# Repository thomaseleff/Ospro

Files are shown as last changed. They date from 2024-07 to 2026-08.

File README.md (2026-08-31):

<html>
    <body>
        <p align="center">
            
        </p>
        <h1 align="center">Ospro</font></h1>
        <p align="center">Better than decent, open source espresso.</p>
    </body>
</html>

> [!IMPORTANT]
> The resources within this repository are under active development and are expected to change significantly over time without guarantee of backwards compatibility.

## Features
- Data logging of espresso extraction metrics (includes temperature and pressure)
- Temperature control via PID-algorithm
- Pressure profiling via PID-algorithm (in-progress)
- Self-hosted web-interface for browsing historical extractions and creating & sharing espresso extraction profiles (upcoming)

**Ospro** is available at an astounding low cost,
- The cheapest commercial-standard espresso machine with a configurable temperature PID, Rancilio Silvia PID Espresso Machine at **```$1,195 USD```**
- The cheapest with fully-integrated software, Decent DE1PRO at **```$3,699 USD```**
- The cheapest with manual pressure control, Rocket R Nine One Dual-Boiler Espresso Machine at **```$6,500 USD```**

The all-in **Ospro** cost-to-build, including the Gaggia Classic (Evo) Pro, competition-level accessories, hardware and software is less than **```$1,000 USD```**.

## Table of contents
- [Parts](./parts/README.md)
- [Guides](./guides/README.md)

# Installation
Instructions for setting-up the Raspberry Pi operating system and Ospro software application.

## Requirements
- Raspberry Pi OS Bookworm (Python 3.11) or Trixie (Python 3.13)
- Python >=3.11
- [uv](https://docs.astral.sh/uv/) for dependency management (dependencies are declared in [pyproject.toml](pyproject.toml))
- Internet connection

## Instructions
1. Flash a micro-SD card with the Raspberry PI OS version from 2019-07-12 using the official [Raspberry Pi Imager](https://www.raspberrypi.com/software/).
2. Once finished, insert the micro-SD card into the Raspberry Pi, then boot.
3. Once the boot process completes, update the software packages by running the following commands in the terminal,
```
sudo apt update
sudo apt full-upgrade
```
4. Open the Raspberry Pi config and enable SPI and I2C. Open the config by running the following command in the terminal,
```
sudo raspi-config
```
5. Reboot.
6. Once the reboot process completes, open the terminal. Navigate to the location of the USB flash drive storage.
```
cd /media/{user}/{usb-mass-storage-device-name}
```
7. Next, clone the main branch of the **Ospro** repository.
```
git clone --branch main https://github.com/thomaseleff/Ospro.git
```
8. Install [uv](https://docs.astral.sh/uv/) (if not already installed).
```
curl -LsSf https://astral.sh/uv/install.sh | sh
```
9. Navigate into the repository and install the Python requirements. On the Raspberry Pi, include the `rpi` extra for the hardware libraries.
```
cd Ospro
uv sync --extra rpi
```
> On non-Raspberry-Pi machines (e.g. for development), install without the extra: `uv sync`.
>
> When running from a USB flash drive, its filesystem (e.g. FAT32/exFAT) may not support the links `uv` needs for the virtual environment. Point the environment at the home directory (on the internal SD card) before syncing:
> ```
> export UV_PROJECT_ENVIRONMENT=/home/{user}/.venv
> ```
10. Run **Ospro**.
```
uv run python main.py
```

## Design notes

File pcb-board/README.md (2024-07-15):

> [!CAUTION]
> The following resources are provided for informational purposes only. The publisher(s) of the resources assume(s) no responsibility for any personal or property damage, loss of functionality or warranty, or other consequences resulting from the use of the guides. Users proceed at their own risk and are advised to seek professional assistance.

# Board
The board guide contains the breadboard layout assets to make the hardware required for the Ospro software application.

## Table of contents
- [Main board (prototype)](main_board_prototype.fzz)

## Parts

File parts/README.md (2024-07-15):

# Parts
Recommended Gaggia Classic (Evo) Pro espresso machine hardware & accessories as well as the full required hardware and electrical components to complete all hardware and software modifications within [Guides](/guides/README.md). Aside from listing the hardware, the following tables also provide a break-down of the total-cost-to-build.

## Espresso machine hardware & accessories

| Recommended | Qty | Price | Source |
| --- | --- | --- | --- |
| Gaggia Classic (Evo) Pro | 1 | $449.99 | [Whole Latte Love](https://www.wholelattelove.com/products/gaggia-classic-evo-pro-semi-automatic-espresso-machine) |
| IMS Nanotech Gaggia Classic Shower Screen | 1 | $29.99 | [Whole Latte Love](https://www.wholelattelove.com/products/ims-nanotech-gaggia-classic-shower-screen) |
| Gaggia Bottomless Filter Holder | 1 | $36.13 | [Amazon](https://www.amazon.com/gp/product/B00JF9WCBW/ref=ox_sc_act_title_5?smid=A1F6X90FK1MD60&psc=1) |
| Baristapro 18g Nanotech Precision Portafilter Basket | 1 | $29.95 | [Whole Latte Love](https://www.wholelattelove.com/products/baristapro-18g-nanotech-precision-portafilter-basket) |
| Small Kitchen Scale, 500g/ 0.01g | 1 | $13.95 | [Amazon](https://www.amazon.com/gp/product/B082CKHBWC/ref=ox_sc_act_title_1?smid=A2E2CPICPY6E5R&th=1) |
| Metallurgica Motta Black Beechwood Competition Tamper, 58.4 mm | 1 | $42.95 | [Amazon](https://www.amazon.com/Motta-Black-Competition-Tamper-ITALY/dp/B077VP7W5K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) |
| **Total** | | **$602.96** | |

| Optional | Qty | Price | Source |
| --- | --- | --- | --- |
| Caffewerks Silicone Group Gasket | 1 | $7.50 | [Whole Latte Love](https://www.wholelattelove.com/products/caffewerks-silicone-group-gasket-73-x-57-x-8-5mm) |
| Normcore 58.5mm Puck Screen | 1 | $14.99 | [Amazon](https://www.amazon.com/gp/product/B09DDC7KMQ/ref=ox_sc_act_title_2?smid=A376RVBG8KFV1A&psc=1) |
| 2 oz Glass Spray Bottles | 1 | $7.99 | [Amazon](https://www.amazon.com/Amber-Glass-Bottles-Essential-Bottle/dp/B08252DJHN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) |
| Metallurgica Motta Leveling Tool, 58.5 mm | 1 | $42.95 | [Amazon](https://www.amazon.com/Metallurgica-Motta-Barista-Espresso-Leveling/dp/B08NF837P9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) |
| **Total** | | **$73.43**  | |

## Primary hardware components

| Key | Description |
| --- | --- |
|:computer: | Computer hardware |
|:thermometer: | Boiler stabilization hardware |
|:droplet: | Temperature controller hardware  |
|:chart_with_upwards_trend:  | Pressure controller hardware |

| Key | Part | Qty | Premium | Source | Budget  | Source |
| ----- | --- | --- | --- | --- | --- | --- |
| 💻 | Raspberry Pi 4 Model B | 1 | $35.00  | [Adafruit](https://www.adafruit.com/product/4295) | $35.00  | Same as premium |
| 💻 | SanDisk 16GB Ultra microSDHC UHS-I memory card with adapter | 1 | $8.45 | [Amazon](https://www.amazon.com/Sandisk-Ultra-Micro-UHS-I-Adapter/dp/B073K14CVB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) | $4.96 | [AliExpress](https://www.aliexpress.us/item/3256805257283122.html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) |
| 💻 | Raspberry Pi official power supply | 1 | $7.95 | [Adafruit](https://www.adafruit.com/product/4298) | $4.72 | [AliExpress](https://www.aliexpress.us/item/3256802124078165.html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) |
| 💻 | 7 inch 1024x600 IPS, touchscreen display mini HDMI monitor | 1 | $79.99  | [Amazon](https://www.amazon.com/APROTII-Raspberry-1024x600-Capacitive-Touchscreen/dp/B0BBT2SLKS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) | $51.43  | [AliExpress](https://www.aliexpress.us/item/3256804751932026.html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) |
| 💻 | Micro HDMI to mini HDMI cable | 1 | $0.00 | (included with the display) | $0.00 | (included with the display) |
| 💻 | SanDisk 16GB Ultra Fit USB 3.1 flash drive | 1 | $7.29 | [Amazon](https://www.amazon.com/dp/B077Y149DL/ref=twister_B0BQ5H62TT?_encoding=UTF8&th=1) | $4.65 | [AliExpress](https://www.aliexpress.us/item/2255800045699642.html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) |
| 💻 | 40 pin GPIO T-Cobbler breakout board with ribbon cable | 1 | $7.95 | [Adafruit](https://www.adafruit.com/product/2028) | $3.11 | [AliExpress](https://www.aliexpress.us/item/3256803505972324.html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) |
| 💻 | Full size breadboard | 1 | $5.95 | [Adafruit](https://www.adafruit.com/product/239) | 3.89 | [AliExpress](https://www.aliexpress.us/item/3256805782396682.html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) |
| 💻 | Various colored solid core wire | 1 | $15.95  | [Adafruit](https://www.adafruit.com/product/1311) | 13.29 | [AliExpress](https://www.aliexpress.us/item/2251832718635676.html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) |
| 💻 | 2 Pin 5 MM PCB mount screw terminal block | 3 | $8.29 | [Amazon](https://www.amazon.com/Pieces-Pinch-Mount-Terminal-Connector/dp/B01MT4LC0F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) | 3.83 | [AliExpress](https://www.aliexpress.us/item/2251832567524817.html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) |
| 💻 | 8 x 10 1/8 IN thick acrylic sheet | 1 | $4.58 | [Menards](https://www.menards.com/main/doors-windows-millwork/acrylic-glass-sheets/amerilux-0-060-thick-non-glare-acrylic-sheets/nga8x10x050/p-1539107081822-c-7551.htm) | $4.58 | Same as premium |
| 💻 | 3/4 IN x 10 FT roll of removable foam mounting tape | 1 | $3.49 | [Menards](https://www.menards.com/main/paint/adhesives-glue-tape/tape/mounting-tape/duck-reg-0-75-x-10-removable-double-sided-foam-mounting-tape/1098147/p-1444442289319-c-1318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) | $3.49 | Same as premium |
| 💻 | Black nylon machine screw and stand-off set - M2.5 thread | 1 | $16.95  | [Adafruit](https://www.adafruit.com/product/3299) | 3.13 | [AliExpress](https://www.aliexpress.us/item/3256803861233916.html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) |
| 💻 | 3D printed enclosure | 1 | $0.00 | OnShape (in-progress) | $0.00 | Same as premium |
| 💻 | 3D printed front end-cap | 1 | $0.00 | OnShape (in-progress) | $0.00 | Same as premium |
| 💻 | 3D printed rear end-cap | 1 | $0.00 | OnShape (in-progress) | $0.00 | Same as premium |
| 💧 | Adafruit K-type thermocouple amplifier - MAX31855 | 1 | $14.95  | [Adafruit](https://www.adafruit.com/product/269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) | $3.94 | [AliExpress](https://www.aliexpress.us/item/3256801134000615.html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) |
| 💧 | K Type thermocouple with M4 Thread | 1 | $7.99 | [Amazon](https://www.amazon.com/gp/product/B07BW7XCB2/ref=ppx_yo_dt_b_search_asin_title?ie=UTF8&psc=1) | $4.34 | [AliExpress](https://www.aliexpress.us/item/3256805310471537.html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) |
| 💧 | Solid state relay 40DA DC SSR | 1 | $14.99  | [Amazon](https://www.amazon.com/gp/product/B01MCWO35P/ref=ppx_yo_dt_b_search_asin_title?ie=UTF8&psc=1) | $3.99 | [AliExpress](https://www.aliexpress.us/item/3256805804433987.html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) |
| 💧 | 220 ohm resistor | 1 | $0.75 | [Adafruit](https://www.adafruit.com/product/2780) | 2.11 | [AliExpress](https://www.aliexpress.us/item/3256801905005351.html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) |
| 💧 | Blue LED | 1 | $5.95 | [Adafruit](https://www.adafruit.com/product/780) | 1.84 | [AliExpress](https://www.aliexpress.us/item/2251832687046532.html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) |
| 💧 | Male 16 AWG spade-connector | 2 | $1.39 | [Menards](https://www.menards.com/main/electrical/electrical-tools-accessories/terminals-connectors/termination-connectors/gardner-bender-reg-16-14-awg-blue-spade-wire-termina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) | $1.39 | Same as premium |
| 💧 | Male 16 AWG disconnect | 2 | $1.34 | [Menards](https://www.menards.com/main/electrical/electrical-tools-accessories/terminals-connectors/termination-connectors/gardner-bender-reg-yellow-male-wire-disconnect/20-14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) | $1.34 | Same as premium |
| 💧 | 1/4 IN OD x 10 FT utility copper tubing | 1 | $6.28 | [Home Depot](https://www.homedepot.com/p/Everbilt-1-4-in-O-D-x-10-ft-Copper-Soft-Type-Refrigeration-Coil-D-04010PS/100344517) | $6.28 | Same as premium |
| 💧 | 1/4 IN OD Compression x 1/4 IN FIP brass adapter fitting | 2 | $9.08 | [Home Depot](https://www.homedepot.com/p/Everbilt-1-4-in-OD-Compression-x-1-4-in-FIP-Brass-Adapter-Fitting-801189/207176825) | $9.08 | Same as premium |
| 💧 | 1/8 IN Barb x 1/4 IN MIP brass adapter fitting | 2 | $8.22 | [Home Depot](https://www.homedepot.com/p/Everbilt-1-8-in-Barb-x-1-4-in-MIP-Brass-Adapter-Fitting-800049/300096270) | $8.22 | Same as premium |
| 💧 | High-temperature silicone foam, 12 IN x 12 IN, 1/4 IN thick, extra soft | 1 | $48.90  | [McMaster-Carr](https://www.mcmaster.com/8608K54/) | $9.28 | [AliExpress](https://www.aliexpress.us/item/3256801394757303.html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) |
| 💧 | High-pressure reinforced silicone rubber tubing for food and beverage, 1/8 IN ID, 23/64 IN OD, 2 FT Length | 1 | $5.55 | [Ebay](https://www.ebay.com/itm/404190884353) | $5.55 | Same as premium |
| 💧 | 5/16 - 5/8 IN stainless steel hose clamp | 4 | $7.52 | [Home Depot](https://www.homedepot.com/p/Everbilt-5-16-5-8-in-Stainless-Steel-Hose-Clamp-6260294/202309384) | $7.52 | Same as premium |
| 💧 | 12 IN Zip-ties | 4 | $8.49 | [Amazon](https://www.amazon.com/HS-Protected-Locking-Plastic-Outdoor/dp/B078NQBSJR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) | $8.49 | [Amazon](https://www.amazon.com/HS-Protected-Locking-Plastic-Outdoor/dp/B078NQBSJR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) |
| 📈 | Adafruit 4-channel I2C-safe Bi-directional logic level converter - BSS138 | 1 | $3.95 | [Adafruit](https://www.adafruit.com/product/757) | $3.30 | [AliExpress](https://www.aliexpress.us/item/2251832174884554.html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) |
| 📈 | Adafruit 16-Bit ADC - 4 Channel with programmable gain amplifier - ADS1115 | 1 | $14.95  | [Adafruit](https://www.adafruit.com/product/1085) | $2.35 | [AliExpress](https://www.aliexpress.us/item/3256805787660372.html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) |
| 📈 | Pressure transducer 1/8 IN NPT thread stainless steel (500 PSI) | 1 | $15.99  | [Amazon](https://www.amazon.com/gp/product/B00RCPDE40/ref=ppx_yo_dt_b_asin_title_o00_s00?ie=UTF8&th=1) | $11.37  | [AliExpress](https://www.aliexpress.us/item/2251832873594937.html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) |
| 📈 | 1/4 IN x 1/8 IN FIP brass reducing coupling fitting | 1 | $4.18 | [Home Depot](https://www.homedepot.com/p/Everbilt-1-4-in-x-1-8-in-FIP-Brass-Reducing-Coupling-Fitting-802059/300096128) | $4.18 | Same as premium |
| 📈 | 25 W 100 OHM high power wirewound rheostat | 1 | $16.99  | [Amazon](https://www.amazon.com/gp/product/B012S6HSJ4/ref=ppx_yo_dt_b_search_asin_title?ie=UTF8&th=1) | $9.90 | [AliExpress](https://www.aliexpress.us/item/3256805007421993.html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) |
| 📈 | 16 AWG 600 V wire (6 FT length) | 1 | $18.89  | [Amazon](https://www.amazon.com/Silicone-Flexible-Stranded-Strands-MILAPEAK/dp/B07CMYVF3J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) | 6.52 | [AliExpress](https://www.aliexpress.us/item/3256805920023343.html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) |
| 📈 | 1/4 IN PET expandable braided sleeving (22 IN length) | 1 | $7.99 | [Amazon](https://www.amazon.com/gp/product/B081MWG8YW/ref=ppx_yo_dt_b_search_asin_title?ie=UTF8&th=1) | 2.09 | [AliExpress](https://www.aliexpress.us/item/3256802548623899.html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) |
| 📈 | Female 16 AWG disconnect | 4 | $2.57 | [Menards](https://www.menards.com/main/electrical/electrical-tools-accessories/terminals-connectors/termination-connectors/gardner-bender-reg-16-14-awg-female-wire-disconnect-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) | $2.57 | Same as premium |
| 📈 | Male 16 AWG disconnect | 2 | $1.34 | [Menards](https://www.menards.com/main/electrical/electrical-tools-accessories/terminals-connectors/termination-connectors/gardner-bender-reg-yellow-male-wire-disconnect/20-14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) | $1.34 | Same as premium |
| 📈 | 1/4 IN shrink wrap (1.5 IN length) | 2 | $8.79 | [Amazon](https://www.amazon.com/gp/product/B07QM8249H/ref=ppx_yo_dt_b_search_asin_title?ie=UTF8&th=1) | 3.07 | [AliExpress](https://www.aliexpress.us/item/3256805006045816.html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) |
| 📈 | [3D printed enclosure](https://cad.onshape.com/documents/64f241d8e2f6bf438afa5b67/w/5135805c6b87d0dba22b77a7/e/a455f75cacce987199a97961) | 1 | $0.00 | [OnShape](https://cad.onshape.com/documents/64f241d8e2f6bf438afa5b67/w/5135805c6b87d0dba22b77a7/e/a455f75cacce987199a97961) | $0.00 | Same as premium |
| 📈 | [3D printed front end-cap](https://cad.onshape.com/documents/64f241d8e2f6bf438afa5b67/w/5135805c6b87d0dba22b77a7/e/b7d37d7233d42274cbf21a53) | 1 | $0.00 | [OnShape](https://cad.onshape.com/documents/64f241d8e2f6bf438afa5b67/w/5135805c6b87d0dba22b77a7/e/b7d37d7233d42274cbf21a53) | $0.00 | Same as premium |
| 📈 | [3D printed rear end-cap](https://cad.onshape.com/documents/64f241d8e2f6bf438afa5b67/w/5135805c6b87d0dba22b77a7/e/9c09796ffe08f1e6f5b5e0ba)  | 1 | $0.00 | [OnShape](https://cad.onshape.com/documents/64f241d8e2f6bf438afa5b67/w/5135805c6b87d0dba22b77a7/e/9c09796ffe08f1e6f5b5e0ba) | $0.00 | Same as premium |
| **Total** | | | **$438.88** | | **$256.14** | |

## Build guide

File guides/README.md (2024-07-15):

> [!CAUTION]
> The following guides are provided for informational purposes only. The publisher(s) of the guides assume(s) no responsibility for any personal or property damage, loss of functionality or warranty, or other consequences resulting from the use of the guides. Users proceed at their own risk and are advised to seek professional assistance.

# Build guides
The build guides provide instructions to make hardware and software modifications to the Gaggia Classic (Evo) Pro espresso machine. These guides include a list of the needed parts (including 3D printer files), tools, and step-by-step assembly instructions.

## Table of contents

#### [Hardware](#hardware-guides)
- [Variable pressure controller](#variable-pressure-controller)
- [Water preheating coil](#water-preheating-coil)

#### [Software](#software-guides)
- [Ospro](#ospro-prototype)

# Hardware guides
Hardware guides cover modifications that involve changing the existing hardware or adding on additional hardware to the espresso machine without the need for software. This means that hardware modifications are a great place to start as they can be made individually without dependence on other hardware or software modifications.

## Variable pressure controller
The variable pressure controller provides manual pressure control via a rotary dial, allowing for full control over the current supplied to the pump throughout extraction. By adjusting the current, the flow rate is adjusted, allowing for a full range of extraction pressures from low pressure pre-infusion (1-3 bars) to 12 bars. Pressure control is vital for proper extraction of nuanced flavors and aromas throughout the brewing process.

### Parts
- 1 x 25 W 100 OHM high power wirewound rheostat
- 1 x 16 AWG 600 V wire (6 FT length)
- 1 x 1/4 IN PET expandable braided sleeving (22 IN length)
- 4 x Female 16 AWG disconnect
- 2 x Male 16 AWG disconnect
- 2 x 1/4 IN shrink wrap (1.5 IN length)
- 1 x [3D printed enclosure](https://cad.onshape.com/documents/64f241d8e2f6bf438afa5b67/w/5135805c6b87d0dba22b77a7/e/a455f75cacce987199a97961)
- 1 x [3D printed front end-cap](https://cad.onshape.com/documents/64f241d8e2f6bf438afa5b67/w/5135805c6b87d0dba22b77a7/e/b7d37d7233d42274cbf21a53)
- 1 x [3D printed rear end-cap](https://cad.onshape.com/documents/64f241d8e2f6bf438afa5b67/w/5135805c6b87d0dba22b77a7/e/9c09796ffe08f1e6f5b5e0ba)
- 8 x M2.5 x 4 MM screws

### Tools
- Wire stripper/cutter
- Wire crimper
- Screwdriver
- 9/16 IN hex wrench
- Lighter/heat gun

### Instructions
> [!CAUTION]
> Prior to making any modifications, unplug the espresso machine power cable completely.

1. Cut the 16 AWG 600 V wire into three sections, 2 x 30 IN sections and 1 x 8 IN section, using the wire stripper/cutter.
2. Cut the 1/4 IN PET expandable braided sleeving into 1 x 22 IN section, burnishing the ends with the lighter/heat gun.
3. Holding the two wires together on one end, feed them through the 1/4 IN PET expandable braided sleeving. Feed the sleeving onto the wires until an equal amount of the wires is remaining at each end.
4. Thread two 1.5 IN sections of 1/4 IN shrink wrap onto the sleeved wire assembly. Fix one section of shrink wrap over each the end of the braided sleeving using the lighter/heat gun, securing it in place.
5. Strip 1/4 IN of wire insulation from both ends of each 30 IN wire as well as both ends of the 8 IN wire.
6. On each 30 IN wire, crimp a female 16 AWG disconnect to one end of the wire assembly and crimp a male 16 AWG disconnect on the other end using the wire crimper. Each wire should have the same type of disconnect on both ends.
7. On the 8 IN section, crimp a female 16 AWG disconnect on each end using the wire crimper.
8. Connect the 8 IN wire to the right wire of the sleeved cable assembly, creating one longer wire with the 8 IN section.
9. Remove the top hold-down nut from the shaft of the rheostat using the hex wrench, then insert the rheostat into the enclosure, pressing the rheostat through the holes in the top of the enclosure. Screw down the hold-down nut and tighten with the hex wrench.
10. Loosen the holding screw of the rheostat knob, then insert the knob onto the shaft of the rheostat. Align the holding screw with the flat knotch of the shaft. Once in place, tighten the holding screw to fix the knob in place with the screwdriver.
11. Thread the end of the shorter wire of the wire assembly with the female disconnect through the right hole of the rear end-plate. Thread the end of the longer wire of the wire assembly with the female disconnect through the center hole of the rear end-plate.
12. Holding the enclosure so that the terminals of the rheostat are facing away, connect the female disconnect of the shorter wire to the left-hand terminal of the rheostat. Connect the female disconnect of the longer wire to the center terminal of the rheostat.
13. Screw the front and rear end-plates to the enclosure with the 8 x M2.5 x 4 MM screws and screwdriver.
14. Unplug the espresso machine power cable.
15. Remove the top plate of the espresso machine.
16. Remove the screws holding the pump assembly to the bottom of the espresso machine enclosure (this is to allow more freedom of movement to manage the wires connected to the pump).
17. Move the espresso machine so that the back of the machine is facing away, then remove the left disconnect from the pump.
18. Attach the male disconnect of the shorter wire to the female disconnect of the wire that used to be attached to the pump.
19. Attach the female disconnect of the longer wire to the left terminal of the pump.
20. Screw down the pump assembly to the bottom of the espresso machine enclosure and replace the top plate of the espresso machine.
21. Plug back in the espresso machine power cable.
22. Turn on the espresso machine, then turn on the brew switch. While brewing, turn the rotary knob of the rheostat. As the knob is turned to the left, the flow of water should decrease. As the knob is turned to the right, the flow of water should increase.

## Water preheating coil
The water pre-heating coil provides an insulated, passively heated boiler intake water line that retains just over 3 oz of water within 10 ft of copper tubing. By passively heating the intake water to the boiler, the boiler is able to maintain a much more stable temperature. Overall, this yields a much more consistent brew temperature during extractions reducing the time between extractions.

### Parts
- 1 x 1/4 IN OD x 10 FT utility copper tubing
- 2 x 1/4 IN OD Compression x 1/4 IN FIP brass adapter fitting
- 2 x 1/8 IN Barb x 1/4 IN MIP brass adapter fitting
- 1 x High-temperature silicone foam, 12 IN x 12 IN, 1/4 IN thick, extra soft
- 1 x High-pressure reinforced silicone rubber tubing for food and beverage, 1/8 IN ID, 23/64 IN OD, 2 FT Length
- 4 x 5/16 - 5/8 IN stainless steel hose clamp
- 4 x 12 IN Zip-ties

### Tools
- Copper tubing cutter
- Tomato sauce jar
- Teflon tape
- Adjustable wrench
- 1/2 IN wrench
- Utility knife
- Screwdriver
- 4 MM hex key
- 5 MM hex key

### Instructions
> [!CAUTION]
> Prior to making any modifications, unplug the espresso machine power cable completely.

1. Inspect the ends of the copper tubing, if either end is not perfectly round, use the copper tubing cutter to remove the damaged section.
2. Place one end of the copper tubing pointing away from you on a flat surface. Holding the tomato sauce jar horizontally on top of the copper tubing, gently wrap the copper tubing around the jar, rolling the jar towards you. Use the flat surface to guide the copper wire around the jar in small sections, carefully avoiding any kinks or crimps in the tubing.
3. Attach the 1/4 IN OD compression fitting to each end of the copper tubing coil. Wrap 3-4 layers of teflon tape around the adapter threads before tightening with the adjustable and 1/2 IN wrenches.
4. Attach the 1/8 IN barb fitting to each end of copper tubing coil. Wrap 3-4 layers of teflon tape around the adapter threads before tightening with the adjustable and 1/2 IN wrenches.
5. Make the boiler insulation template,
   - Print out the boiler insulation template
   - Tape the pages where indicated, cutting out the template following the solid line.
6. Secure the boiler insulation template to the high-temperature silicone foam sheet and trace along the edge of the template, transfering the template to the foam sheet. Mark the placement of through-holes. Cut along the marked line with the utility knife and poke through the foam with a screwdriver to create the through-holes. 
7. With the copper coil positioned vertically and the upper inlet positioned pointing away from you, wrap the silicone foam around the coil so that the square cutout of the silicone foam is at the bottom of the coil. Secure the silicone foam in place lightly with the zip-ties.
8. Unplug the espresso machine power cable.
9. Remove the top plate of the espresso machine.
10. Remove the wires connected to the brew and steam thermostats and the heating elements. Unscrew the ground bracket holding the fuse in place, moving the ground wire and fuse wire assembly to the side. Remove the wires connected to the front-panel rocker switches.
11. Remove the machine screws holding the boiler assembly to the espresso machine enclosure using the 4 MM hex key (this is to allow more freedom of movement to fit the copper coil and silicone foam around the boiler).
12. Remove the machine screws holding the steam wand assembly to the boiler using the 5 MM hex key.
13. Remove the machine screws holding the 3-way solenoid valve to the boiler using the 4 MM hex key.
14. Remove the espresso machine boiler from the espresso machine.
15. Remove the pink braided tubing from the inlet barb of the boiler.
16. Place the copper coil and silicone foam assembly over the top of the boiler. Rotate the square cutout so that it is positioned over the 3-way solenoid value outlet.
17. Press the 1 FT high-pressure reinforced silicone tubing onto the lower barb fitting of the copper coil, securing in place with a hose clamp, tightening with the screwdriver. Press the other end of the 1 FT high-pressure reinforced silicone tubing onto inlet barb of the boiler, securing in place with a hose clamp, tightening with the screwdriver.
18. Insert the boiler back into the espresso machine enclosure, reversing steps 11-13.
19. Press the pink braided tubing onto the upper barb fitting of the copper coil, securing in place with a hose clamp, tightening with the screwdriver.
20. Reinstall the ground wire bracket and fuse. Insert the top sheet of silicone foam, then reconnect the wires to the brew and steam thermostats and the heating elements. Reconnect the wires to the front-panel rocker switches.
21. Screw down the boiler assembly to the bottom of the espresso machine enclosure and replace the top plate of the espresso machine.
22. Plug back in the espresso machine power cable.
23. Turn on the espresso machine. Then, turn on the brew switch until water flows out of the grouphead.

# Software guides
Software guides cover modifications that involve changing the existing hardware as well as adding on additional hardware and software to the espresso machine.

## Ospro (prototype)
The main board contains the Raspberry Pi as well as the other core hardware required for the Ospro software application. The hardware below supports the following features,
- User-interface display
- Espresso extraction data tracking (temperature and pressure over-time) and storage
- Temperature control

### Parts
- 1 x Raspberry Pi 4 Model B
- 1 x SanDisk 16GB Ultra microSDHC UHS-I memory card with adapter
- 1 x Raspberry Pi official power supply
- 1 x 7 inch 1024x600 IPS, touchscreen display mini HDMI monitor
- 1 x Micro HDMI to mini HDMI cable
- 1 x SanDisk 16GB Ultra Fit USB 3.1 flash drive
- 1 x 40 pin GPIO T-Cobbler breakout board with ribbon cable
- 1 x K Type thermocouple with M4 Thread
- 1 x Adafruit K-type thermocouple amplifier - MAX31855
- 1 x Solid state relay 40DA DC SSR
- 1 x 220 ohm resistor
- 1 x Blue LED
- 1 x Pressure transducer 1/8 IN NPT thread stainless steel (500 PSI)
- 1 x Adafruit 16-Bit ADC - 4 Channel with programmable gain amplifier - ADS1115
- 1 x Adafruit 4-channel I2C-safe Bi-directional logic level converter - BSS138
- 1 x Full size breadboard
- 3 x 2 Pin 5 MM PCB mount screw terminal block
- 1 x 8 x 10 1/8 IN thick acrylic sheet
- 1 x 3/4 IN x 10 FT roll of removable foam mounting tape
- 4 x 10 MM M2.5 standoffs and nuts
- 4 x M2.5 screws
- 1 x 1/4 IN x 1/8 IN FIP brass reducing coupling fitting
- 2 x 16 AWG spade-connector
- 2 x 16 AWG male disconnect
- Various colored solid core wire

### Tools
- Wire stripper/cutter
- Needle nose pliers
- Screwdriver
- Utility knife
- Drill and bits
- Teflon tape
- Thermal paste
- Adjustable wrench

### Instructions
> [!CAUTION]
> Prior to making any modifications, unplug the espresso machine power cable completely.

1. Insert the T-cobbler, thermocouple amplifier (MAX31855), bi-directional logic level converter (BSS138), gain amplifier (ADS1115), blue LED and resistor into a full-size breadboard according to the following diagram.
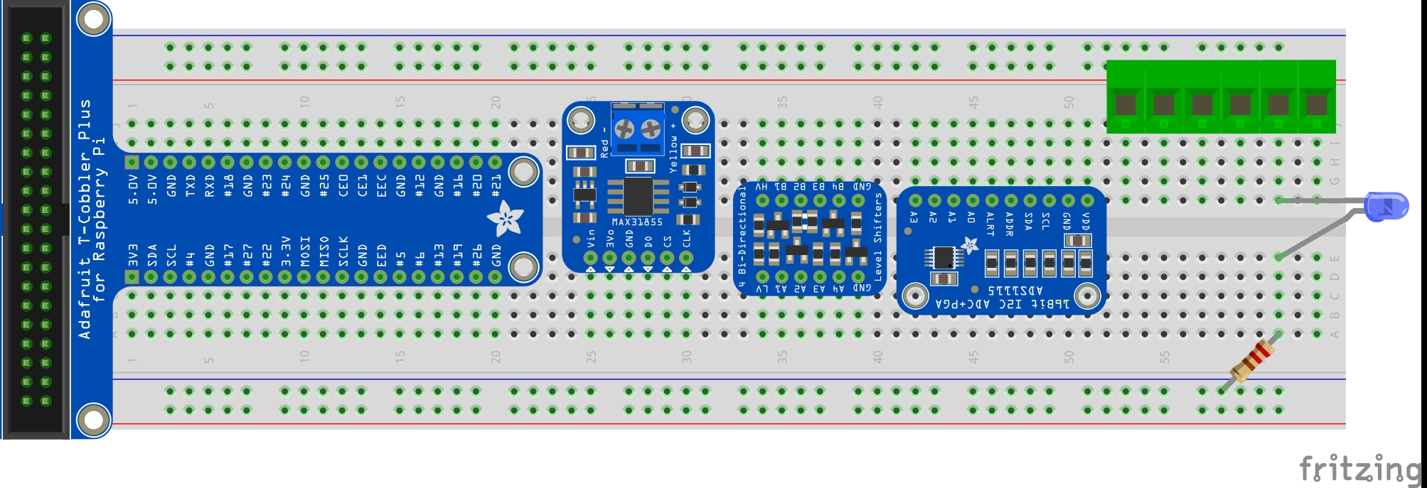
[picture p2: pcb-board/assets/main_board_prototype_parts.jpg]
Breadboard part layout


2. Connect the components to the T-cobbler using the solid core wire. Cut sections of the wire slightly longer than each run, strip ~1/8" of sleeving from each end, then create 90-degree bends using the needle nose pliers. Insert the wires into the breadboard according to the following diagram.
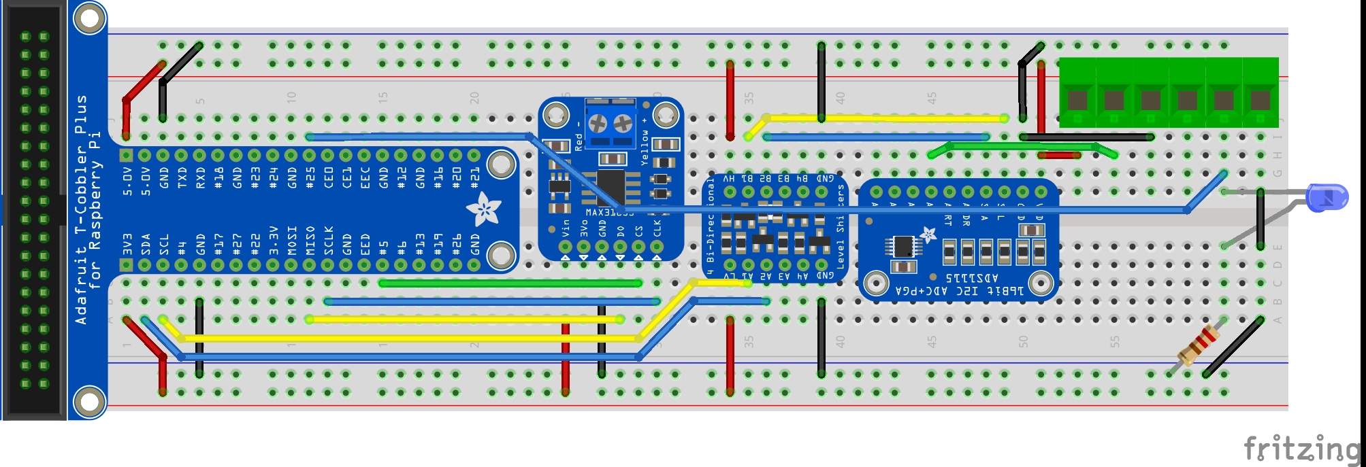
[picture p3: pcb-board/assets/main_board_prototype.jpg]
Breadboard wiring layout


3. Connect the Raspberry Pi to the T-cobbler using the 40 pin ribbon cable, ensuring that the pins on the Raspberry Pi are correctly connected. Improperly connecting the Raspberry Pi could damage the Pi itself and the parts.
4. Connect the k-type thermocouple to the screw terminals of the thermocouple amplifier (MAX31855) according to the silkscrean layout on the amplifier PCB.
5. Connect the red, green and black leads of the pressure transducer to the first, second and third screw terminals (starting on the left) of the PCB mounted screw terminal blocks.
6. Connect a wire to the fifth screw terminal (starting on the left) to the positive input terminal of the solid state relay. Connect a wire to the 6th screw terminal (starting on the left) to the negative input terminal of the solid state relay.
7. Apply two strips of the foam adhesive tape to the back of the breadboard and adhere it to the surface of the acrylic sheet.
8. Holding the Raspberry Pi onto the surface of the acrylic sheet, mark each mounting holes position on the acrylic. Drill a hole through the acrylic on each mark. Secure the Raspberry Pi to the acrylic sheet using the 4 x 10 MM M2.5 standoffs and nuts.
9. Unplug the espresso machine power cable.
10. Remove the top plate of the espresso machine.
11. Remove the steam wand assembly. Attach the 1/4 IN x 1/8 IN FIP brass reducing coupling to the steam outlet. Wrap 3-4 layers of teflon tape around the adapter threads before tightening with the adjustable wrench.
12. Attach the pressure transducer to the reducing coupling. Wrap 3-4 layers of teflon tape around the threads before tightening with the adjustable wrench.
13. Remove the brew thermostat from the boiler. Add a small amount of thermal paste to the M4 threads of the thermocouple. Screw in the thermocouple where the brew thermostat used to be located on the boiler.
14. Attach the leads that used to be attached to the brew thermostat to the output terminals of the solid state relay.
15. Apply two strips of the foam adhesive tape to the back of the solid state relay and adhere it to the inside of the espresso machine enclosure.
16. Replace the top plate of the espresso machine.
17. Connect the 7 IN touchscreen display to the Raspberry Pi. Place the screen on top of the espresso machine.
18. Insert the 16 GB USB drive, and connect a keyboard and mouse to the Raspberry Pi.
19. Follow the [Installation](/README.md#installation) instructions to setup the Raspberry Pi Ospro software application.

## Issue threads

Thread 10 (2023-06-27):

Resolve application of the deadzone range

thomaseleff, 2023-06-27:
Currently, the deadzone range is converted between Celsius and Fahrenheit, which gives an unreliable difference depending on the magnitude of the temperature set-point.

**To Do:**

- Refactor read_pid.py so that the deadzone range is always evaluated against a value in Celsius
- Remove logic within dashboard.py that converts the deadzone range to Fahrenheit

Closed 2024-07-15.

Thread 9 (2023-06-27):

Revise read_temp() within temp.Sensor() to assign the previous temp value

thomaseleff, 2023-06-27:
Currently, the error handling within `read_temp()` of the `temp.Sensor()` class passes rather than assigning a valid value for the current temperature. This causes challenges within the ~/modules as the logic to retrieve the previous temp value becomes more complex.

**To Do:**

- Add a new variable within the `temp.Sensor()` class that is created upon initialization, `self.previousTemp`
  - Assign a null value upon initialization
- Update the value of `self.previousTemp` each successful `read_temp()` function call. On `RuntimeError`, return the value of `self.previousTemp` as `temp`.
- Add a new config.json parameter into the tPID section that identifies the allowed error between temp readings. When the resulting error between the previous and current temp reading exceeds the error value, return the value of `self.previousTemp` as `temp`.
  - Update temp_pid.py to leverage the new config.json parameter wherever the error of the temp value is evaluated.

Closed 2024-07-15.

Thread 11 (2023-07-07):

Refactor the temperature conversion functions out of the Sensor() class

thomaseleff, 2023-07-07:
Currently, the temperature conversion functions are accessible only through the Sensor() class, which is not ideal as the class must first be initialized in order to use these functions.

**To Do:**
- Move the temperature conversion functions to be outside the Sensor() class
- Wherever temperature conversions occur within dashboard.py (or any other module), leverage the new functions

Closed 2024-07-15.

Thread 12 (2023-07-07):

Improve plot fitting

thomaseleff, 2023-07-07:
Currently, the Espresso Extraction Performance and Pressure Profiler plots do not fit perfectly in the center (see attached image)

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

**To Do:**
- Adjust the positioning of the plot layout so that the plot fits more directly in the center of the window

Closed 2024-07-15.

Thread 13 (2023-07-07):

Issue incrementing the extraction counter

thomaseleff, 2023-07-07:
Currently, if multiple extractions are saved for the same day, the counter does not increment.

**To Do:**

- Investigate the cause for the counter no longer incrementing after each saved extraction
- Implement a fix to resolve the issue

Closed 2024-07-15.

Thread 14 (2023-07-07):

Issue in pressure profiler plotting callback

thomaseleff, 2023-07-07:
Currently, the duration slides can lead to Value Errors within the pressure profiler plotting callback function.

```
ValueError: x and y must have same first dimension, but have shapes (240,) and (241,)
bgerror failed to handle background error.
    Original error:
    Error in bgerror: can't invoke "tk" command: application has been destroyed
bgerror failed to handle background error.
    Original error: invalid command name "2048996356224check_dpi_scaling"
    Error in bgerror: can't invoke "tk" command: application has been destroyed
```

**To Do:**
- Investigate the cause of the Value Error within the pressure profiler plotting callback function
- Implement a fix to resolve the issue

Closed 2024-07-15.

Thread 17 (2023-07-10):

Implement a method to derive pressure profile nodes from a user generated profile

thomaseleff, 2023-07-10:
Currently, the pressure profile nodes within the 'Settings' module are defaulted to 9 bars, which leads to issues when a user-generated profile is "edited" within the 'Pressure Profiler' module (all nodes are defaulted to 9 bars, regardless of the true pressure time series). When saved, the user-generated profile is then overwritten with the nodes (which are currently invalid).

**To Do:**
- Write a simulation module that can perform an evaluation of methods to determine,
  1. Whether there is or is not a pre-infusion period and, if so, the pressure and duration of that period.
  2. The time intervals and pressure values at each quartile of the extraction period, including the start and end time of the period.
- The simulation module should,
  1. Simulate a large number of pressure profiles (their parameters and time series of data)
  2. Evaluate different methods to determine (i.) and (ii.) above, producing a visual plot identifying the performance of the method (if applicable) and the visualized result
  3. Produce a result of the method, which should be in the form of a pressure profile config.

thomaseleff, 2023-07-10:
Potential methods to identify (i.),
1. On the time series, evaluate whether the rate of change between the initial and each incremental point is within or outside-of some bounds. If the rate of change is less than some maximum rate of change criteria for more than 1 second, assume there is a pre-infusion period. Otherwise, assume no pre-infusion.
    - Either evaluate the rate of change as a direct calculation of the slope, or,
    - Fit a linear regression based on the smoothed data time series.
2. Evaluate a histogram of the pressure time series. If the histogram is bi-modal, with one mode centered below 6 bars, and the count of observations in that mode is > 10, then assume there is a pre-infusion period. Otherwise, assume no pre-infusion.

thomaseleff, 2023-07-10:
Potential methods to identify (ii.),
1. Determine the quartiles of the time series and assign the pressure value at each interval as the observed pressure from the user-generated profile (evaluate with and without smoothing).
2. Determine the quartiles of the time series and assign the pressure value as a fitted value to a polynomial curve that describes the time series.

thomaseleff, 2023-08-21:
Alternatively, derive a static lookup table of simulated pressure profile values that can be compared to the user generated profile. Select the profile from the static lookup table that has the least squared error when compared to the user generated profile.

thomaseleff, 2023-09-03:
The final method introduces a new algorithm within the ospro library within ~/algorithms/espresso_profile_fitting_algorithm.py. The method solves an "OLS"-like algorithm, which produces a series of pressure profile nodes as a pressure profile from user-generated extraction time series data. Based on the result of simulating solutions for the prior ~2.5 years of espresso extraction data, the method produces a solution within 2 seconds max, with an average run time of 0.37 seconds.

Closed 2024-07-15.

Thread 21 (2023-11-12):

Add Initial Breadboard Design and Revise the Code to Account for New Pin-Assignments

thomaseleff, 2023-11-12:
**To Do:**

- Design a breadboard prototype circuit that supports the following components,
  - 40-pin header (compatible with up to a Raspberry Pi 4 Model B) broken out by a T-cobbler
  - Temperature sensor and controller hardware module
  - Pressure sensor hardware module
- Revise the code so that _all_ the pin-assignments are configurable within ```~/config.txt```

Closed 2024-07-15.

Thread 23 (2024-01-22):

Create a design document of the Ospro UI

thomaseleff, 2024-01-22:
**To Do:**
- Create a design document of the Ospro UI in Adobe XD
- Within the design document, detail the layout of the application as well as the technical specifications of the design elements (component attributes like corner rounding, color, etc.)

thomaseleff, 2024-01-27:
**Jan. 27, '24,**
- Demo'd Adobe XD and reviewed alternative design applications. Although, Adobe XD seems to be ideal for now, providing state animations, sizing and attribute parameters that can be translated directly to code.
- Reviewed immediate scope and priorities,
  1. Document the current design of the web-application frames within Adobe XD, representing them in their current state within a design document
  2. Investigate how to define variables for colors/dimensions so that multiple elements can be updated with a single change
  3. Publish the design document within ```v0.1.0```

timothyfaris, 2024-01-31:
The design document can be viewed at - https://xd.adobe.com/view/4f511d09-1411-4a42-8692-a3616be853f0-1a02/grid

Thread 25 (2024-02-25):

Add exception handling to read_pressure()

thomaseleff, 2024-02-25:
If there is no recognized i2c-device at the expected address, the `read_pressure()` function currently returns an uncaught exception.

**To Do:**
- Add exception handling to `read_pressure()` that handles an `OSError` exception and reports the error in the console.

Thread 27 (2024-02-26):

Leverage differential pressure sensor reading rather than single-ended

thomaseleff, 2024-02-26:
**To Do:**
- Switch the sensor class method to leverage the differential reads, rather than single-ended

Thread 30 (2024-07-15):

Overheating

thomaseleff, 2024-07-15:
Occasionally, the espresso machine can enter into unstable behavior where the temperature controller forces the machine to overheat.

**To Do:**
- Review the logic that handles temperature reading exceptions
- Review the logic that treats inaccurate temperature readings
- Propose various solutions below for improving both the temperature reading exceptions and treatment of inaccurate temperature readings

thomaseleff, 2024-10-17:
**Revisions**:

`temp.py`
- Removed handling of `RuntimeError` exceptions raised while reading the current temperature value
- Removed handling of error within the temperature readings

`temp_pid.py`
- Reduced the threshold for over-heating to the set-point rather than an arbitrary temperature
- Added try/except to exit the process with an I/O error code during `RuntimeError` exceptions raised while reading the current temperature value (`main.py` will restart the temperature controller subprocess automatically when `temp_pid.py` exits with the I/O error code).

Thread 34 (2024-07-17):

Resolve issue allowing for multiple frames to be opened

thomaseleff, 2024-07-17:
**To Do**:
- Before creating new top-level frames, check if the frame already exists. When the frame exists, do not re-create it.

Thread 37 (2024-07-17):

Implement coffee tag module

thomaseleff, 2024-07-17:
**To Do:**
- Implement a new window to configure coffee attributes as tags.
- Include the following required tag categories,
  - Roaster
  - Origin
  - Specific origin (if `Origin` = "Single origin")
  - Roast
  - Process

timothyfaris, 2025-06-17:
- this data could be extremely useful to roasters.
- hinges upon consistency in grind (i think).
- - this poses a slight issue with the Eureka (as you know).

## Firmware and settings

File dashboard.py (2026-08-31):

""" Dashboard UI """

import os
import sys
import re
import math
import textwrap
import tkinter as tk
import customtkinter
import pandas as pd
import numpy as np
import datetime as dt
import matplotlib.pyplot as plt
from matplotlib.backends.backend_tkagg import FigureCanvasTkAgg
from scipy.stats import pearsonr
from PIL import Image

from ospro import exceptions, errors
from ospro.platform import factory
from ospro.sensors import temp as ts
from ospro.sensors import pressure as ps
import ospro.utils.utils as utils

# Initialize global variables
idling = True
extracting = False
flashing = False
counter = 0
temperatureLst = []
pressureLst = []
config = utils.read_config(
    configLoc=os.path.join(
        os.path.dirname(__file__),
        'config',
        'config.json'
    )
)

# Load the platform interface
try:
    GPIO = factory.load_interface(
        dev=config['session']['dev']
    )
except exceptions.InvalidPlatformError:
    sys.exit(errors.PLATFORM_ERRNO)

# Setup the interface
GPIO.setup(
    config['extraction']['pin'],
    GPIO.OUT
)

# Initialize temperatore sensor
tSensor = ts.Sensor(dev=config['session']['dev'])

# Initialize pressure sensor
pSensor = ps.Sensor(dev=config['session']['dev'])

# Assign extraction ID
if os.path.isdir(config['session']['diagnosticsLoc']):
    databaseLst = os.listdir(config['session']['diagnosticsLoc'])
    databaseLst = [
        item for item in databaseLst if (
            ('Diagnostics_' in item)
            and ('.csv' in item)
        )
    ]

    # If no diagnostic files exists, then re-assign the ID
    if databaseLst == []:
        uniqueID = 1
    else:
        uniqueID = int(
            max([
                int(Item.split('_')[1]) for Item in databaseLst
            ]) + 1
        )
else:
    print('ERROR: Invalid Diagnostics Location Provided in config.')
    print(
        '       Please Provide Real Directory Path for %s.' % (
            config['session']['diagnosticsLoc']
        )
    )
    sys.exit()


# Define application navigation functions
def button_press():
    """
    Variables
    ---------------------------------------------------------------------

    Description
    ---------------------------------------------------------------------

    """

    print('Click')


def error(
    message
):
    """
    Variables
    ---------------------------------------------------------------------
    message                 = <str> Text to display in the error frame

    Description
    ---------------------------------------------------------------------
    Raises an error frame object.
    """

    # Create error frame
    error = create_toplevel_frame(
        master=root,
        title='Error',
        width=342,
        height=129,
        numCols=4,
        numRows=4,
        fullscreen=False
    )

    # Declare error frame components
    labelError = customtkinter.CTkLabel(
        error,
        text=' '.join(
            ['Error:', message]
        )
    )
    buttonOkay = customtkinter.CTkButton(
        error,
        height=config['format']['buttonHeight'],
        width=config['format']['buttonWidth'],
        corner_radius=config['format']['buttonHeight'],
        text='Okay',
        command=lambda: back(error)
    )

    # Pack error frame components
    labelError.grid(
        column=0,
        row=0,
        columnspan=3,
        rowspan=2,
        padx=config['format']['padX'],
        pady=config['format']['padY'],
        sticky=tk.N+tk.S+tk.E+tk.W
    )
    buttonOkay.grid(
        column=2,
        row=2,
        columnspan=2,
        rowspan=1,
        padx=config['format']['padX'],
        pady=config['format']['padY'],
        sticky=tk.N+tk.S+tk.E
    )


def close():
    """
    Variables
    ---------------------------------------------------------------------

    Description
    ---------------------------------------------------------------------
    Closes the root window object.
    """

    global idling, extracting, flashing

    idling = False
    extracting = False
    flashing = False

    # Exit
    root.destroy()
    sys.exit()


def back(
    frame
):
    """
    Variables
    ---------------------------------------------------------------------
    frame                   = <class> CTkFrame object to close

    Description
    ---------------------------------------------------------------------
    Closes a frame object.
    """

    # Close the top-frame to reveal the previous frame
    frame.destroy()


def save_extraction(
    labelCounter,
    buttonStart,
    buttonStop,
    buttonReset,
    buttonPlot,
    buttonSave,
    buttonSettings,
    buttonBack
):
    """
    Variables
    ---------------------------------------------------------------------
    labelCounter            = <class> CTkLabel object
    buttonStart             = <class> CTkButton object
    buttonStop              = <class> CTkButton object
    buttonReset             = <class> CTkButton object
    buttonPlot              = <class> CTkButton object
    buttonSave              = <class> CTkButton object
    buttonSettings          = <class> CTkButton object
    buttonBack              = <class> CTkButton object

    Description
    ---------------------------------------------------------------------
    Writes the espresso extraction data to the ~/diagnostics/ folder and
    re-sets the state of {labelCounter}, {buttonStart}, {buttonStop},
    {buttonReset}, {buttonPlot}, {buttonSave}, {buttonSettings}, and
    {buttonBack}.
    """

    global idling, extracting, flashing
    global counter, temperatureLst, pressureLst, uniqueID
    global tkCounter, tkTempValue, tkPresValue

    # Initialize the extraction dataframe
    extractionDf = pd.DataFrame()

    # Generate a time series list
    timeLst = [
        round(item / 10, 1)
        for item in list(
            range(
                0,
                len(temperatureLst)
            )
        )
    ]

    # Read pressure profile config
    profile = read_profile(
        profileName=config['settings']['profile']
    )

    # Generate extraction data series
    username = [
        ', '.join([
            config['user']['last'],
            config['user']['first']
        ])
    ] * len(temperatureLst)
    uniqueIDLst = [uniqueID] * len(temperatureLst)
    date = [
        dt.datetime.now().strftime('%d/%b/%Y').upper()
    ] * len(temperatureLst)
    time = [
        dt.datetime.now().strftime('%H:%M:%S')
    ] * len(temperatureLst)
    tUnit = [
        config['settings']['scale']
    ] * len(temperatureLst)
    pUnit = ['Bars'] * len(temperatureLst)
    maxDuration = [max(timeLst)] * len(temperatureLst)
    minTemp = [min(temperatureLst)] * len(temperatureLst)
    maxTemp = [max(temperatureLst)] * len(temperatureLst)
    minPressure = [min(pressureLst)] * len(temperatureLst)
    maxPressure = [max(pressureLst)] * len(temperatureLst)
    tempSetPoint = [tkSetPoint.get()] * len(temperatureLst)

    if config['settings']['profile'].upper().strip() == 'MANUAL':
        profileName = [config['settings']['profile']] * len(temperatureLst)
        presProf = [0] * len(temperatureLst)
    else:
        profileName = [config['settings']['profile']] * len(temperatureLst)
        presProf = profile['settings']['pressureProfileLst']

    # Build dataframe from extraction data series'
    extractionDf = pd.DataFrame(
        data={
            'User': username,
            'UniqueID': uniqueIDLst,
            'Date': date,
            'Time': time,
            'Duration': timeLst,
            'Temperature': temperatureLst,
            'TUnit': tUnit,
            'Pressure': pressureLst,
            'PUnit': pUnit,
            'MaxDuration': maxDuration,
            'MinTemp': minTemp,
            'MaxTemp': maxTemp,
            'MinPressure': minPressure,
            'MaxPressure': maxPressure,
            'TempSetPoint': tempSetPoint,
            'Profile': profileName,
            'ProfileValues': presProf
        },
        columns=[
            'User',
            'UniqueID',
            'Date',
            'Time',
            'Duration',
            'Temperature',
            'TUnit',
            'Pressure',
            'PUnit',
            'MaxDuration',
            'MinTemp',
            'MaxTemp',
            'MinPressure',
            'MaxPressure',
            'TempSetPoint',
            'Profile',
            'ProfileValues'
        ]
    )

    # Output dataframe
    extractionDf.to_csv(
        os.path.join(
            config['session']['diagnosticsLoc'],
            '.'.join([
                '_'.join([
                    'Diagnostics',
                    str(uniqueID),
                    date[0].replace('/', '')
                ]),
                'csv'
            ])
        ),
        sep=',',
        index=False
    )

    # Configure application state
    idling = True
    extracting = False
    flashing = False
    counter = 0
    temperatureLst = []
    pressureLst = []

    # Update application components
    tkCounter.set(float(round(counter / 10, 1)))
    if config['settings']['scale'] == 'F':
        tkTempValue.set(
            ts.convert_to_f(
                tSensor.read(set_point=config['tPID']['setPoint'])
            )
        )
    else:
        tkTempValue.set(
            tSensor.read(set_point=config['tPID']['setPoint'])
        )
    tkPresValue.set(pSensor.read(set_point=config['pPID']['setPoint']))

    labelCounter.configure(text_color=theme['CTkLabel']['text_color'])
    buttonStart.configure(state='normal')
    buttonStop.configure(state='disabled')
    buttonReset.configure(state='disabled')
    buttonPlot.configure(state='disabled')
    buttonSave.configure(state='disabled')
    buttonSettings.configure(state='normal')
    buttonBack.configure(state='normal')

    # Increment unique ID
    uniqueID += 1

    # Trigger idling
    idle()


def save_settings(
    frame
):
    """
    Variables
    ---------------------------------------------------------------------
    frame                   = <class> CTkFrame object to close

    Description
    ---------------------------------------------------------------------
    Writes the config dictionary object to ~/config/config.json and
    closes the frame.
    """

    # Write config
    try:
        utils.write_config(
            configLoc=os.path.join(
                config['session']['configLoc'], 'config.json'
            ),
            config=config
        )
    except FileNotFoundError as e:
        print(e)
        sys.exit()

    # Close the top-level frame
    frame.destroy()


def read_profile(
    profileName
):
    """
    Variables
    ---------------------------------------------------------------------
    profileName             = <str> Name of a pressure profile config

    Description
    ---------------------------------------------------------------------
    Reads and validates a pressure profile config.
    """

    # Read pressure profile config
    try:
        profile = utils.read_config(
                configLoc=os.path.join(
                    config['session']['configLoc'],
                    'profiles',
                    '.'.join([
                        profileName,
                        'json'
                    ])
                )
            )
    except (FileNotFoundError, IOError) as e:
        print(e)
        sys.exit()

    # Read dtypes config
    try:
        dtype = utils.read_config(
                configLoc=os.path.join(
                    config['session']['configLoc'],
                    'profiles',
                    'dtypes.json'
                )
            )
    except FileNotFoundError as e:
        print(e)
        sys.exit()

    # Validate pressure profile config
    try:
        utils.validate_config(
            profile,
            dtype
        )
    except TypeError as e:
        print(e)
        sys.exit()

    return profile


def check_profile(
    frame,
    customProfile,
    tkProfileName
):
    """
    Variables
    ---------------------------------------------------------------------
    frame                   = <class> CTkFrame object to close
    customProfile           = <dict> Dictionary object of the espresso
                                profile settings
    tkProfileName           = <class> CTkLabel object

    Description
    ---------------------------------------------------------------------
    Validates the {customProfile} dictionary object and writes the
    pressure profile config object to ~/config/profiles/.
    """

    # Update profile name value
    customProfile['settings']['name'] = tkProfileName.get()

    # Check if profile name already exists
    if os.path.isdir(
        os.path.join(
            config['session']['configLoc'],
            'profiles'
        )
    ):
        profileLst = sorted(
            [
                item.split('.')[0] for item in os.listdir(
                    os.path.join(
                        config['session']['configLoc'],
                        'profiles'
                    )
                ) if (
                    (item.split('.')[0].upper().strip() != 'DTYPES') and
                    (item.split('.')[1].upper() == 'JSON')
                )
            ]
        )

    if customProfile['settings']['name'] in profileLst:

        # Create warning frame
        warning = create_toplevel_frame(
            master=root,
            title='Warning',
            width=342,
            height=129,
            numCols=4,
            numRows=4,
            fullscreen=False
        )

        # Define warning messages
        message0 = '[%s] already exists.' % (
            customProfile['settings']['name']
        )
        message1 = 'Do you want to overwrite it?'

        # Declare warning frame components
        labelWarning0 = customtkinter.CTkLabel(
            warning,
            text=message0
        )
        labelWarning1 = customtkinter.CTkLabel(
            warning,
            text=message1
        )
        buttonNo = customtkinter.CTkButton(
            warning,
            height=config['format']['buttonHeight'],
            width=config['format']['buttonWidth'],
            corner_radius=config['format']['buttonHeight'],
            text='No',
            command=lambda: back(warning)
        )
        buttonYes = customtkinter.CTkButton(
            warning,
            height=config['format']['buttonHeight'],
            width=config['format']['buttonWidth'],
            corner_radius=config['format']['buttonHeight'],
            text='Yes',
            command=lambda: save_profile(
                frame,
                customProfile,
                True,
                warning
            )
        )

        # Pack warning frame components
        labelWarning0.grid(
            column=0,
            row=0,
            columnspan=3,
            rowspan=1,
            padx=config['format']['padX'],
            pady=config['format']['padY'],
            sticky=tk.N+tk.S+tk.W
        )
        labelWarning1.grid(
            column=0,
            row=1,
            columnspan=3,
            rowspan=1,
            padx=config['format']['padX'],
            pady=config['format']['padY'],
            sticky=tk.N+tk.S+tk.E+tk.W
        )
        buttonNo.grid(
            column=0,
            row=2,
            columnspan=2,
            rowspan=1,
            padx=config['format']['padX'],
            pady=config['format']['padY'],
            sticky=tk.N+tk.S+tk.W
        )
        buttonYes.grid(
            column=2,
            row=2,
            columnspan=2,
            rowspan=1,
            padx=config['format']['padX'],
            pady=config['format']['padY'],
            sticky=tk.N+tk.S+tk.E
        )

    else:
        # Set empty warning frame
        warning = False

        # Output the pressure profile config
        save_profile(
            frame,
            customProfile,
            False,
            warning
        )


def delete_profile(
    selectProfile
):
    """
    Variables
    ---------------------------------------------------------------------
    selectProfile           = <class> CTkComboBox object

    Description
    ---------------------------------------------------------------------
    Deletes the {selectProfile} from ~/config/profiles/.
    """

    global config

    # Check if 'Manual' profile is selected
    if config['settings']['profile'].upper().strip() == 'MANUAL':
        error(
            '[Manual] profile cannot be deleted.'
        )
    else:

        # Check if presure profile config exists
        try:
            if '.'.join([config['settings']['profile'], 'json']) in os.listdir(
                os.path.join(
                    config['session']['configLoc'],
                    'profiles'
                )
            ):

                # Create confirmation frame
                confirm = create_toplevel_frame(
                    master=root,
                    title='Confirmation',
                    width=342,
                    height=129,
                    numCols=4,
                    numRows=4,
                    fullscreen=False
                )

                # Define confirmation message
                message = (
                    'Are you sure you want to delete [%s]?' % (
                        config['settings']['profile']
                    )
                )

                # Declare confirmation frame components
                labelConfirm = customtkinter.CTkLabel(
                    confirm,
                    text=message
                )
                buttonNo = customtkinter.CTkButton(
                    confirm,
                    height=config['format']['buttonHeight'],
                    width=config['format']['buttonWidth'],
                    corner_radius=config['format']['buttonHeight'],
                    text='No',
                    command=lambda: back(confirm)
                )
                buttonYes = customtkinter.CTkButton(
                    confirm,
                    height=config['format']['buttonHeight'],
                    width=config['format']['buttonWidth'],
                    corner_radius=config['format']['buttonHeight'],
                    text='Yes',
                    command=lambda: delete_callback(
                        confirm,
                        selectProfile
                    )
                )

                # Pack confirmation frame components
                labelConfirm.grid(
                    column=0,
                    row=0,
                    columnspan=3,
                    rowspan=2,
                    padx=config['format']['padX'],
                    pady=config['format']['padY'],
                    sticky=tk.N+tk.S+tk.E+tk.W
                )
                buttonNo.grid(
                    column=0,
                    row=2,
                    columnspan=1,
                    rowspan=1,
                    padx=config['format']['padX'],
                    pady=config['format']['padY'],
                    sticky=tk.N+tk.S+tk.W
                )
                buttonYes.grid(
                    column=2,
                    row=2,
                    columnspan=1,
                    rowspan=1,
                    padx=config['format']['padX'],
                    pady=config['format']['padY'],
                    sticky=tk.N+tk.S+tk.E
                )

            else:
                error(
                    '%s does not exist. Refresh the Settings.' % (
                        config['settings']['profile']
                    )
                )

        except FileNotFoundError:
            print(
                'ERROR: %s does not exist.' % (
                    os.path.join(
                        config['session']['configLoc'],
                        'profiles'
                    )
                )
            )
            sys.exit()


def save_profile(
    frame,
    customProfile,
    inputWarning,
    warningFrame
):
    """
    Variables
    ---------------------------------------------------------------------
    frame                   = <class> CTkFrame object to close
    customProfile           = <dict> Dictionary object of the espresso
                                profile settings
    inputWarning            = <bool> Parameter to close the warning frame
    warningFrame            = <class> Additional CTKFrame object to close

    Description
    ---------------------------------------------------------------------
    Saves the espresso profile settings from {customProfile} to
    ~/config/profiles/.
    """

    # Close warning frame
    if inputWarning:
        warningFrame.destroy()

    # Write pressure profile config
    try:
        utils.write_config(
            configLoc=os.path.join(
                    config['session']['configLoc'],
                    'profiles',
                    '.'.join([
                        customProfile['settings']['name'],
                        'json'
                    ])
                ),
            config=customProfile
        )
    except FileNotFoundError as e:
        print(e)
        sys.exit()

    # Close the top-level frame
    frame.destroy()
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

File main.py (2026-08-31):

""" Ospro """

from typing import Union
import os
import sys
import time
import subprocess
from ospro import logging, errors
from pytensils import config

# Initialize global variables
RUNNING: bool = True
DIR_NAME: Union[str, os.PathLike] = os.path.abspath(
    os.path.dirname(__file__)
)
EXECUTABLE: Union[str, os.PathLike] = os.path.abspath(sys.executable)
SESSION: dict = {
    'running': RUNNING,
    'assetsLoc': os.path.join(
        DIR_NAME, 'assets'
    ),
    'configLoc': os.path.join(
        DIR_NAME, 'config'
    ),
    'diagnosticsLoc': os.path.join(
        DIR_NAME, 'diagnostics'
    ),
    'modulesLoc': DIR_NAME,
    'controllersLoc': DIR_NAME,
    'sensorsLoc': os.path.join(
        DIR_NAME, 'ospro', 'sensors'
    ),
    'utilsLoc': os.path.join(
        DIR_NAME, 'ospro', 'utils'
    )
}


# Define app-orchestration functions
def initialize(
    session_object: dict,
    Logging: logging.Logger
) -> config.Handler:
    """ Checks for the dashboard, temp_pid and pressure_pid modules. Reads,
    validates and updates ~/config.json and returns a
    `pytensils.config.Handler` object.

    Parameters
    ----------
    session_object: `dict`
        Dictionary object containing the parameters essential to the session.
    Logging: `logging.Logger`
        Logging object for debug console logging.
    """

    # Check dashboard
    if os.path.isfile(
        os.path.join(
            session_object['modulesLoc'], 'dashboard.py'
        )
    ):
        session_object['dashboard'] = True

    # Check temperature PID
    if os.path.isfile(
        os.path.join(
            session_object['controllersLoc'], 'temp_pid.py'
        )
    ) and (session_object['dashboard']):
        session_object['tempPID'] = True

    # Check pressure PID
    if os.path.isfile(
        os.path.join(
            session_object['controllersLoc'], 'pressure_pid.py'
        )
    ) and (session_object['dashboard']):
        session_object['pressurePID'] = True

    # Read config
    Config = config.Handler(path=os.path.join(session_object['configLoc']))
    Config.data['session'] = {**Config.data['session'], **session_object}

    # Validate config
    if Config.validate(
        dtypes=config.Handler(
            path=os.path.join(session_object['configLoc']),
            file_name='dtypes.json'
        ).to_dict()
    ):

        # Logging
        Logging.debug('NOTE: Config validation completed successfully.')

        # Update config with session parameters
        Config.write()

    return Config


def poll(
    app: subprocess.Popen,
    executable_path: Union[str, os.PathLike],
    app_path: Union[str, os.PathLike]
):
    """ Checks the status of the application and re-starts it when not
    running.

    Parameters
    ----------
    app: `subprocess.Popen`
        Class instance of the application.
    executable_path: `Union[str, os.PathLike]`
        The local file-path of the Python executable.
    app_path: `Union[str, os.PathLike]`
        The local file-path of the application entrypoint.
    """

    if app.poll() is None:
        pass

    elif app.returncode in errors.FATAL:
        app = False

        # Logging
        Logging.error(
            ' '.join([
                '%sERROR: Invalid platform.' % (logging.COLORS['red']),
                'The {raspberry-pi} platform requires ARM-architecture',
                'and the {rpi} hardware libraries',
                '(install with `uv sync --extra rpi`).%s' % (logging.RESET)
            ])
        )

    elif app.returncode > 0:

        # Restart
        app = subprocess.Popen([executable_path, app_path])

        # Logging
        Logging.debug(
            'NOTE: {%s} restarted successfully.' % (os.path.basename(app_path))
        )

    else:
        app = False

    return app


if __name__ == '__main__':

    # Setup logging
    Logging = logging.get_ospro_logger()

    # Initialize the application
    Config = initialize(session_object=SESSION, Logging=Logging)

    # Initialize the dashboard-UI
    if Config.data['session']['dashboard']:
        dashboard_app = subprocess.Popen(
            [
                EXECUTABLE,
                os.path.join(
                    Config.data['session']['modulesLoc'],
                    'dashboard.py'
                )
            ]
        )

    # Initialize the temperature controller
    if Config.data['session']['tempPID']:
        temp_pid_app = subprocess.Popen(
            [
                EXECUTABLE,
                os.path.join(
                    Config.data['session']['controllersLoc'],
                    'temp_pid.py'
                )
            ]
        )

    # Initialize the pressure controller
    if Config.data['session']['pressurePID']:
        pass
        # pressure_pid_app = subprocess.Popen(
        #     [
        #         EXECUTABLE,
        #         os.path.join(
        #             Config.data['session']['controllersLoc'],
        #             'pressure_pid.py'
        #         )
        #     ]
        # )

    while Config.data['session']['running']:

        # Read config
        Config = config.Handler(
            path=os.path.join(
                Config.data['session']['configLoc']
            )
        )

        try:
            if dashboard_app:
                dashboard_app = poll(
                    app=dashboard_app,
                    executable_path=EXECUTABLE,
                    app_path=os.path.join(
                        Config.data['session']['modulesLoc'],
                        'dashboard.py'
                    )
                )

                temp_pid_app = poll(
                    app=temp_pid_app,
                    executable_path=EXECUTABLE,
                    app_path=os.path.join(
                        Config.data['session']['controllersLoc'],
                        'temp_pid.py'
                    )
                )

            else:

                # Terminate applications
                Config.data['session']['running'] = False
                Config.write()

        except KeyboardInterrupt:

            # Terminate applications
            Config.data['session']['running'] = False
            Config.write()

        time.sleep(5)

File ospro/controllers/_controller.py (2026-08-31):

""" Generic controller """

from ospro.platform import factory


class GenericController():
    """ A `class` that represents a generic controller.

    Parameters
    ----------
    dev: `bool`
        `True` or `False`, whether dev-mode is enabled.
    output_pin: `int`
        Pin number that identifies the pulse width modulation pin.
    """

    def __init__(
        self,
        dev: bool,
        output_pin: int
    ):
        """ Creates an instance of the controller.

        Parameters
        ----------
        dev: `bool`
            `True` or `False`, whether dev-mode is enabled.
        output_pin: `int`
            The general-purpose input/output pin that sets the
                pulse-width power output for the controller.
        """

        # Assign class variables
        self.output_pin: int = output_pin

        # Load the platform interface
        GPIO = factory.load_interface(dev=dev)

        # Setup the platform interface for the controller
        GPIO.setup(
            self.output_pin,
            GPIO.OUT
        )

        # Create a pulse-width modulation controller
        self.controller = GPIO.PWM(
            self.output_pin,
            600
        )

        # Start the controller
        self.controller.start(0)

    def start(
        self
    ):
        """ Starts the duty cycle of the controller. """
        self.controller.start(0)

    def stop(
        self
    ):
        """ Stops the duty cycle of the controller. """
        self.controller.stop()

    def update_duty_cycle(
        self,
        output: float
    ):
        """ Changes the duty cycle of the controller.

        Parameters
        ----------
        output: `float`
            The pulse-width modulation output duty cycle.
        """
        self.controller.ChangeDutyCycle(output)

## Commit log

2022-03-05 Initial Repository Commit
    [Diagnostics_6_01FEB2021.csv, config.txt, config_backup.txt]
2024-01-07 Resolves #21
    [main-board.fzz, main_board_prototype.fzz]
2024-10-21 Resolves attribute error #30
    [raspberry_pi.py]
2024-10-21 Resolves runtime error #30
    [raspberry_pi.py]
2024-10-21 Resolves pin state error #30
    [dashboard.py]
2026-08-31 Adopt uv + pyproject, modernize Python to 3.13
    Replace flat requirements*.txt pins with a uv-managed pyproject.toml +
    uv.lock, and bring the project onto Python >=3.11 (target 3.13) with
    modern dependency versions.
    - Fix numpy 2.x / scipy incompatibilities in the profile-fitting algorithm
    (drop private numpy.core.multiarray.interp -> np.interp; import
    scipy.ndimage.uniform_filter1d explicitly).
    - Migrate the pressure sensor from legacy Adafruit_ADS1x15 to
    adafruit-circuitpython-ads1x15, mirroring the temp sensor's board/busio
    pattern. Guard the dev-mode read against float set-points.
    - Author pyproject.toml (core deps + `rpi` optional extra), pin .python-version
    to 3.13, commit uv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
    [dashboard.py, factory.py, main.py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]
